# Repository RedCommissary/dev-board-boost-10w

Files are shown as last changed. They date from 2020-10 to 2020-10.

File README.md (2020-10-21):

## Плата разработчика DC/DC boost в режиме CC/CV
Устройство предназначается для изучения основ проектирования силовых преобразователей и снижения порога вхождения в разработку.
Основой служит топология синхронный boost, а алгорит CC/CV реализуется для питания мощного светодиода. Питание преобразователя
осуществляется через тот же порт USB type C, через который выводятся логи и состоянии устройства.

Вид преобразователя

## 1. Технические параметры

* Тип питания: *USB type C*
* Входное напряжение: *5В ± 10%*
* Выходное напряжение: *6...12В*
* Номинальный ток: *3А*
* Защиты: *OVP, OCP, UVLO, перегрев*
* Интерфейсы: *USB*
* Габаритные размеры: *60х40х8 мм*

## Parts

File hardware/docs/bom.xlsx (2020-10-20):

Designator | Value | PartNumber | Manufacturer | Quantity | Comment | HelpURL
C1, C11 | 470pF | CL10C471JB8NNNC | Yageo | 2 | Ceramic capacitor, 470pF, NPO, ±5%, 50V, 0603, -55...+125°C | https://www.digikey.com/product-detail/en/samsung-electro-mechanics/CL10C471JB8NNNC/1276-1168-1-ND/3889254
C2, C3, C9, C10 | 22μF | CL32B226KAJNNNE | Samsung | 4 | Ceramic capacitor, 22μF, X7R, ±10%, 25V, 1210, -55...+125°C | https://www.digikey.com/product-detail/en/samsung-electro-mechanics/CL32B226KAJNNNE/1276-3392-1-ND/3891478
C4, C5, C6, C15, C16, C25 | 0.01μF | CL10B103KB8NNNC | Samsung | 6 | Ceramic capacitor, 0.01μF, X7R, ±10%, 50V, 0603, -55...+125°C | https://www.digikey.com/product-detail/en/samsung-electro-mechanics/CL10B103KB8NNNC/1276-1009-1-ND/3889095
C7 | 1μF | CL10B105KA8NNNC | Samsung | 1 | Ceramic capacitor, 1μF, X7R, ±10%, 25V, 0603, -55...+125°C | https://www.digikey.com/product-detail/en/samsung-electro-mechanics/CL10B105KA8NNNC/1276-1184-1-ND/3889270
C8, C12, C13, C26, C31, C32, C34 | 4.7μF | CL10B475KQ8NQNC | Samsung | 7 | Ceramic capacitor, 4.7μF, X7R, ±10%, 6.3V, 0603, -55...+125°C | https://www.digikey.com/product-detail/en/samsung-electro-mechanics/CL10B475KQ8NQNC/1276-2087-6-ND/3892601
C14, C20, C21, C22, C23, C24, C27, C28, C33, C35 | 0.1μF | CL10B104KB8NNNL | Samsung | 10 | Ceramic capacitor, 0.1μF, X7R, ±10%, 50V, 0603, -55...+125°C | https://www.digikey.com/product-detail/en/samsung-electro-mechanics/CL10B104KB8NNNL/1276-CL10B104KB8NNNLCT-ND/10320686
C17, C18, C19 | 2.2μF | CL10B225KP8NFNC | Samsung | 3 | Ceramic capacitor, 2.2μF, X7R, ±10%, 10V, 0603, -55...+125°C | https://www.digikey.com/product-detail/en/samsung-electro-mechanics/CL10B225KP8NFNC/1276-2016-1-ND/3890102
C29, C30 | 12pF | CL10C120JB8NNNC | Samsung | 2 | Ceramic capacitor, 12pF, NPO, ±10%, 50V, 0603, -55...+125°C | https://www.digikey.com/product-detail/en/samsung-electro-mechanics/CL10C120JB8NNNC/1276-1254-1-ND/3889340
D1 |  | INA180A3IDBVR | Texas Instruments | 1 | IC current monitor, ±1.5%, 100V/V, -0.3...+26V, -40...+125°C, SOT23-5 | https://www.digikey.com/product-detail/en/texas-instruments/INA180A3IDBVR/296-47654-1-ND/8133023
D2 |  | MP1907GQ-Z | Monolithic Power Systems | 1 | Half-bridge gate driver, 100V, 500kHz, ±2.5A, supply 4.5...18V, -40...+125°C, 10-VFDFN (3x3) | https://www.digikey.com/product-detail/en/monolithic-power-systems-inc/MP1907GQ-Z/1589-1544-1-ND/9433310
D3 |  | TLV62568DBV | Texas Instruments | 1 | DC/DC buck converter, input 2.5...5.5V, 1.5MHz, output 0.6V, 1A, -40...+85°C, SOT23-5 | https://www.digikey.com/product-detail/en/texas-instruments/TLV62568DBVT/296-47387-1-ND/7688580
D4 |  | STM32F334C4T6 | STMicroelectronics | 1 | IC microcontroller, 32-Bit, Cortex-M4, 72MHz, 64KB, 12KB, 2...3.6V, -40...+85°C, 48-LQFP | https://www.digikey.com/en/products/detail/stmicroelectronics/STM32F334C4T6/4989170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
D5 |  | CP2102N-A02-GQFN28 | Silicon Labs | 1 | IC usb-to-uart bridge, USB2.0, 3...3.6V, -40...+85°C, 28-VFQFN | https://www.digikey.com/product-detail/en/silicon-labs/CP2102N-A02-GQFN28/336-5889-ND/9863477
FU1 |  | ERB-RG3R00V | Panasonic | 1 | ='='Electromechanics relay'+', '+'32VDC'+', '+'3A'+', '+'1206 case'+', '+Temperature' | https://www.digikey.com/product-detail/en/panasonic-electronic-components/ERB-RG3R00V/P16741CT-ND/4280098
L1 | 33μH | SRP1038C-330M | Bourns | 1 | Fixed inductor, 33μH, ±20%, SRP1038C series, 4A, -40...+125°C | https://www.digikey.com/product-detail/en/bourns-inc/SRP1038C-330M/SRP1038C-330MCT-ND/10249152
L2 | 10μH | SDR0302-100ML | Codaca | 1 | Fixed inductor, 10μH, ±20%, SP32 series, 900mA, -40...+125°C | https://www.digikey.com/product-detail/en/bourns-inc/SDR0302-100ML/SDR0302-100MLCT-ND/2127048
L3 | 10μH | LQM18FN100M00D | Murata Electronics | 1 | Fixed inductor, 10μH, ±20%, 0603, 50mA, -55...+125°C | https://www.digikey.com/product-detail/en/murata-electronics-north-america/LQM18FN100M00D/490-4025-1-ND/1016285
R1 | 0.02R | PF1206FRF070R02L | Yageo | 1 | Resistor film, 0.02R, ±1%, 1206, 0.25W, -55...+125°C | https://www.digikey.com/product-detail/en/yageo/PF1206FRF070R02L/311-0-02AJCT-ND/2178365
R2, R3, R17, R30, R31, R32, R34, R36, R39, R40, R43 | 1k | RC0603FR-071KL | Yageo | 11 | Resistor film, 1k, ±1%, 0603, 0.1W, -55...+125°C | https://www.digikey.com/product-detail/en/yageo/RC0603FR-071KL/311-1-00KHRCT-ND/729790
R4, R5, R41, R42 | 22R | RC0603FR-0722RL | Yageo | 4 | Resistor film, 22R, ±1%, 0603, 0.1W, -55...+125°C | https://www.digikey.com/product-detail/en/yageo/RC0603FR-0722RL/311-22-0HRCT-ND/730002
R6 | 47k | RC0603FR-0747KL | Yageo | 1 | Resistor film, 47k, ±1%, 0603, 0.1W, -55...+125°C | https://www.digikey.com/product-detail/en/yageo/RC0603FR-0747KL/311-47-0KHRCT-ND/730200
R7, R8, R21, R27, R28, R29 | 120R | RC0603JR-07120RL | Yageo | 6 | Resistor film, 120R, ±5%, 0603, 0.1W, -55...+125°C | https://www.digikey.com/product-detail/en/yageo/RC0603JR-07120RL/311-120GRCT-ND/729653
R9, R19, R22, R23 | 10k | RC0603FR-0710KL | Yageo | 4 | Resistor film, 10k, ±1%, 0603, 0.1W, -55...+125°C | https://www.digikey.com/product-detail/en/yageo/RC0603FR-0710KL/311-10-0KHRCT-ND/729827
R10, R15 | 1R6 | RC0603JR-071R6L | Yageo | 2 | Resistor film, 1R6, ±5%, 0603, 0.1W, -55...+125°C | https://www.digikey.com/product-detail/en/yageo/RC0603JR-071R6L/311-1-6GRCT-ND/729638
R11, R12, R13, R14, R16, R24, R25, R26, R37, R38 | 10k | RC0603JR-0710KL | Yageo | 10 | Resistor film, 10k, ±5%, 0603, 0.1W, -55...+125°C | https://www.digikey.com/product-detail/en/yageo/RC0603JR-0710KL/311-10KGRCT-ND/729647
R18 | 0.2R | RL1210FR-070R2L | Yageo | 1 | Resistor film, 0.2R, ±1%, 1210, 0.5W, -55...+125°C | https://www.digikey.com/product-detail/en/yageo/RL1210FR-070R2L/311-0-2NACT-ND/3886121
R20 | 45k3 | RC0603FR-0745K3L | Yageo | 1 | Resistor film, 45k3, ±1%, 0603, 0.1W, -55...+125°C | https://www.digikey.com/product-detail/en/yageo/RC0603FR-0745K3L/311-45-3KHRCT-ND/730192
R33 | 4k7 | NCP18XM472J03RB | Murata | 1 | NTC resistor, 4k7, ±5%, 0603, 3500K, -55...+125°C | https://www.digikey.com/en/products/detail/murata-electronics/NCP18XM472J03RB/588460
R35, R44, R45 | 5k1 | RC0603FR-075K1L | Yageo | 3 | Resistor film, 5k1, ±1%, 0603, 0.1W, -55...+125°C | https://www.digikey.com/product-detail/en/yageo/RC0603FR-075K1L/311-5-10KHRCT-ND/730215
SB1, SB2, SB3 |  | PTS636 SM43 | C&K | 3 | Tactile button, 6x3.5mm | https://www.digikey.com/product-detail/en/c-k/PTS636-SM43-SMTR-LFS/CKN12310-1-ND/10071745
VD1, VD2 |  | 150060VS75000 | Wurth | 2 | LED, 20mA, 2V, 0603, -55...+150°C | https://www.digikey.com/product-detail/en/w-rth-elektronik/150060VS75000/732-4980-1-ND/4489904
VD3, VD9 |  | 150060BS75000 | Wurth | 2 | LED, 20mA, 3.2V, 0603, -55...+150°C | https://www.digikey.com/product-detail/en/w-rth-elektronik/150060BS75000/732-4966-1-ND/4489893, https://www.digikey.com/product-detail/en/wurth-electronics-inc/150060BS75000/732-4966-1-ND/4489893
VD4, VD5, VD6, VD7 |  | 150060RS75000 | Wurth | 4 | LED, 20 mA, 2V, 0603, -55...+150°C | https://www.digikey.com/product-detail/en/w-rth-elektronik/150060RS75000/732-4978-1-ND/4489899
VD8 |  | 150060YS75000 | Wurth | 1 | LED, 20mA, 2V, 0603, -55...+150°C | https://www.digikey.com/product-detail/en/wurth-electronics-inc/150060YS75000/732-4981-1-ND/4489907
VT1, VT2 |  | RQ3G100GNTB | Rohm Semiconductor | 2 | MOSFET N-channel transistor, 40V, 10A, 8.4nC, 2W, 14.3mOhm, 615pF, 8-PowerVDFN (3x3), -55...+150°C | https://www.digikey.com/product-detail/en/rohm-semiconductor/RQ3G100GNTB/RQ3G100GNTBCT-ND/5042551
X3 |  | SM05B-GHS | JST | 1 | Connector, 5pin, 1.25mm, 50VDC, 1A | https://www.digikey.com/product-detail/en/jst-sales-america-inc/SM05B-GHS-TB-LF-SN/455-1567-1-ND/807835
X4 |  | TYPE-C-31-M-12 | Korean Hroparts | 1 | USB Type C, 3A | https://lcsc.com/product-detail/USB-Type-C_Korean-Hroparts-Elec-TYPE-C-31-M-12_C165948.html
Z1 |  | ECS-80-12-33-JGN-TR | ECS | 1 | Crystal, 8MHz, 12pF, ±30ppm, case 3225, -40...+85°C | https://www.digikey.com/product-detail/en/ecs-inc/ECS-80-12-33-JGN-TR/50-ECS-80-12-33-JGN-CT-ND/10478769

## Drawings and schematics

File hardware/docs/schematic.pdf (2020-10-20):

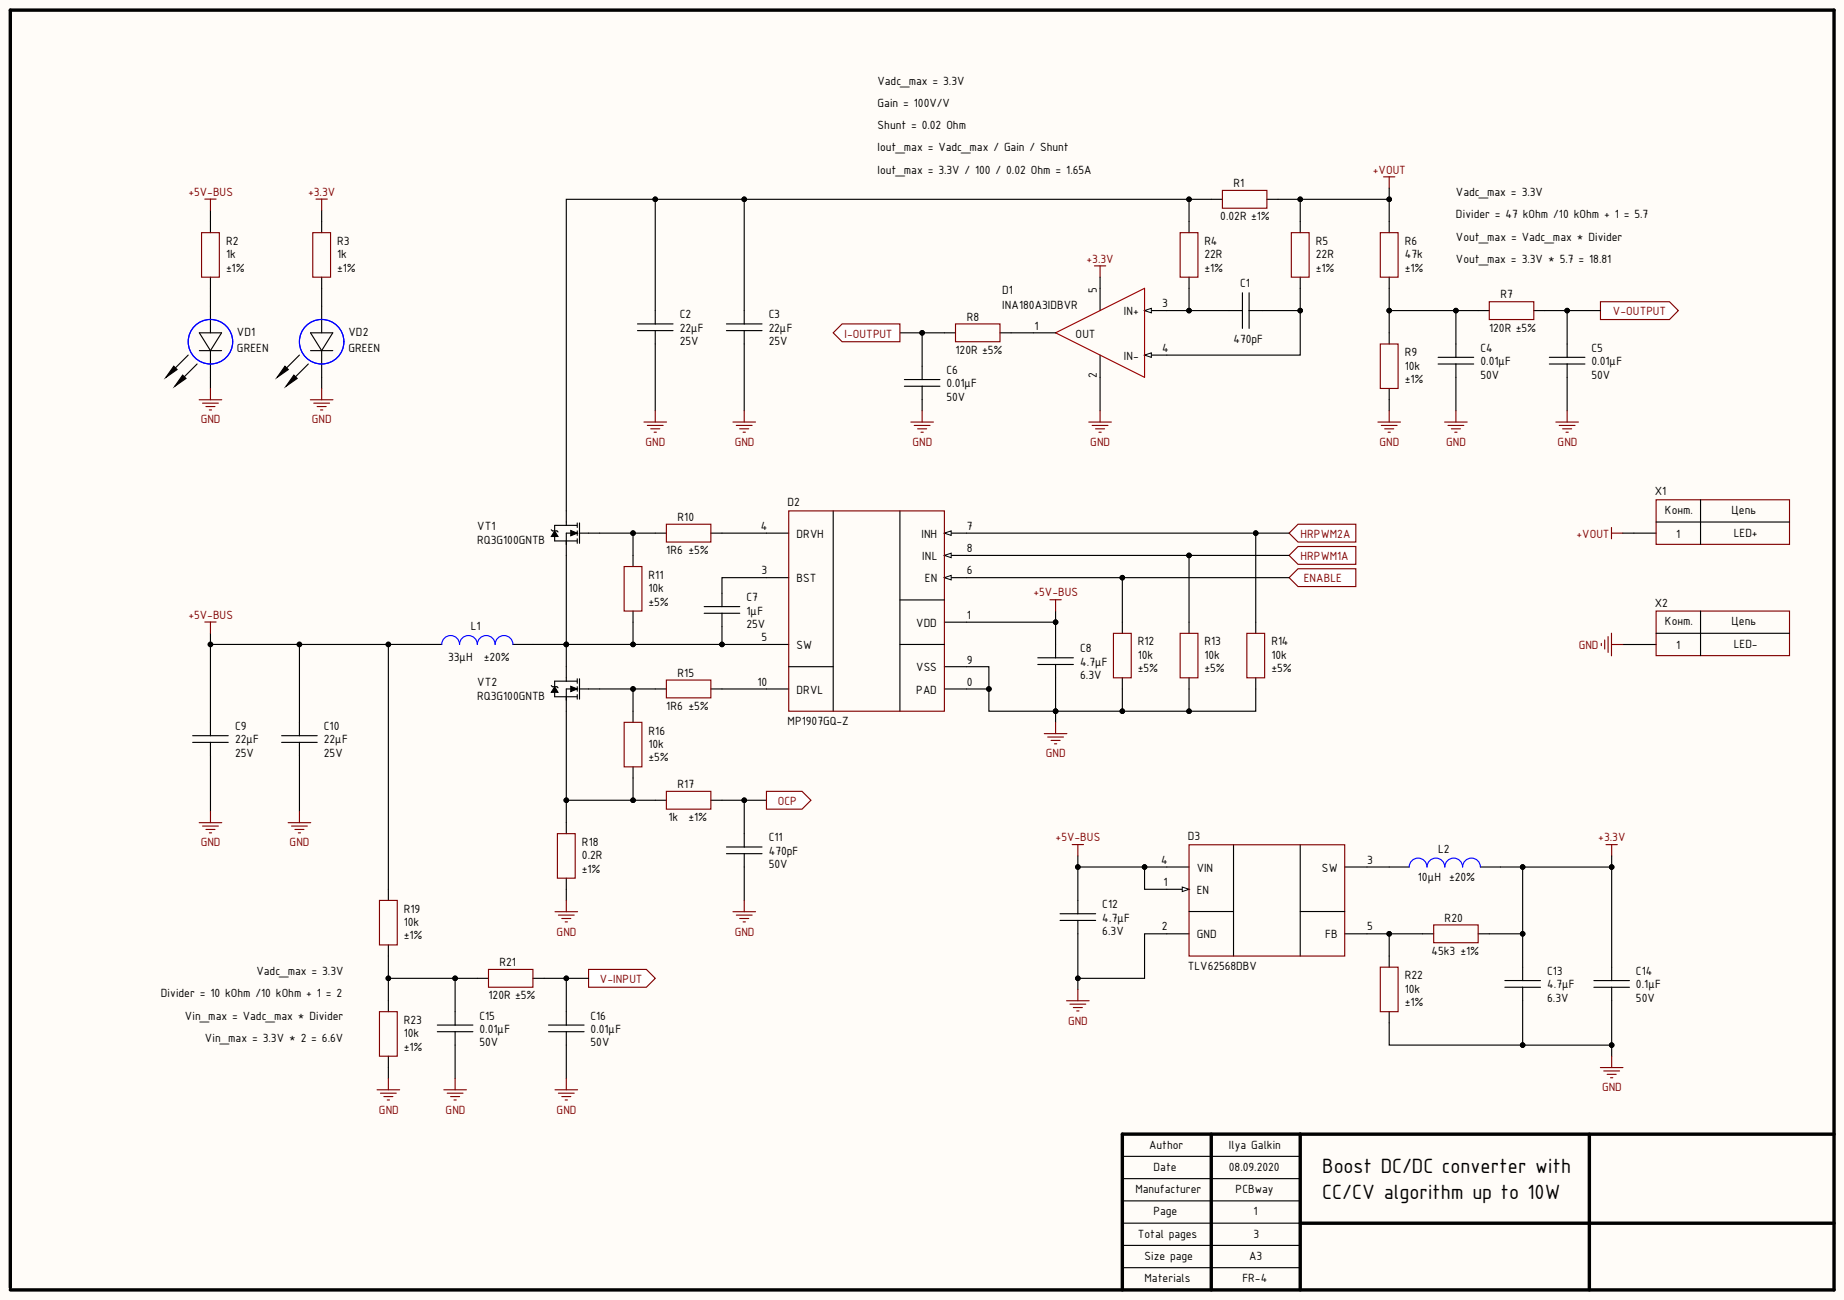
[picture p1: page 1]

Конт. | Цепь

1 | LED+

1 | LED-

Author | Ilya Galkin | Boost DC/DC converter with CC/CV algorithm up to 10W

Date | 08.09.2020

Manufacturer | PCBway

Page

Total pages

Size page | A3

Materials | FR-4

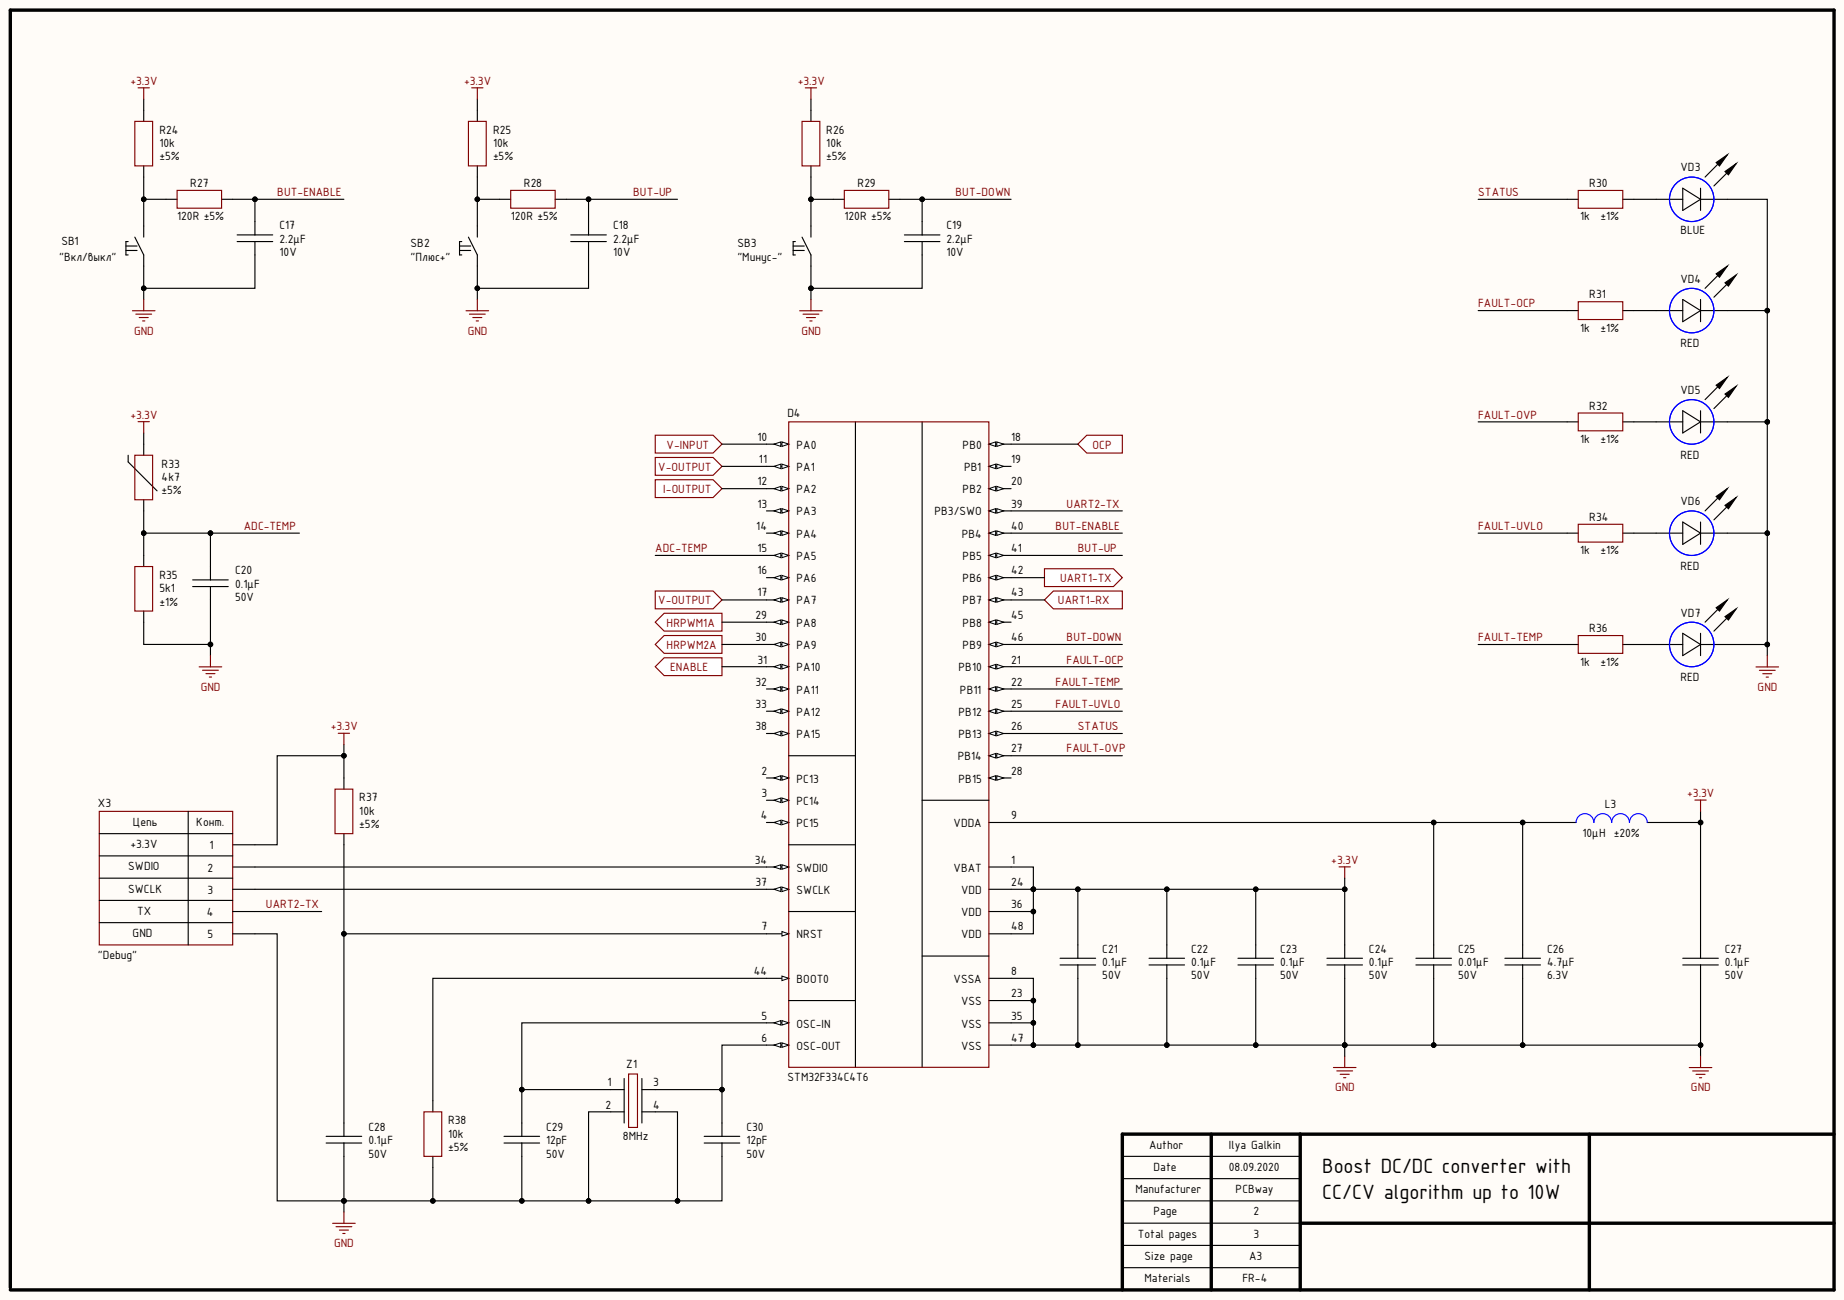
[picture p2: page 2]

PC15 4 | VBAT VDD VDD

Цепь | Конт.

SWDIO | 2

SWDIO 34 | 1 +3.3V 0.1μF | 0.01μF | 4.7μF

SWCLK | 3
4 | UART2-TX TX

SWCLK 37 | 24

NRST 7 | 36 | 0.1μF | 0.1μF | 0.1μF

GND | 5

Author | Ilya Galkin | Boost DC/DC converter with CC/CV algorithm up to 10W

Date | 08.09.2020

Manufacturer | PCBway

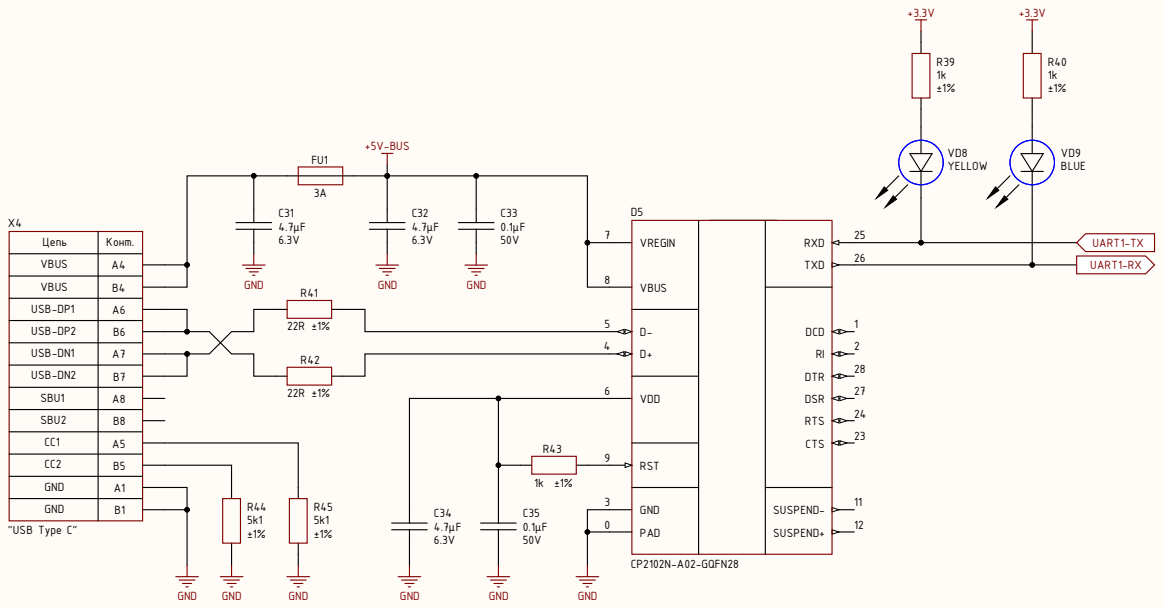
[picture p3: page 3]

Цепь | Конт.

VBUS | A4

VBUS | B4

USB-DP1 | A6

USB-DP2 | B6

USB-DN1 | A7

USB-DN2 | B7
SBU1 | A8 | 22R ±1%

SBU2 | B8

R43 | RST 9

Author | Ilya Galkin | Boost DC/DC converter with CC/CV algorithm up to 10W

Date | 08.09.2020

Manufacturer | PCBway

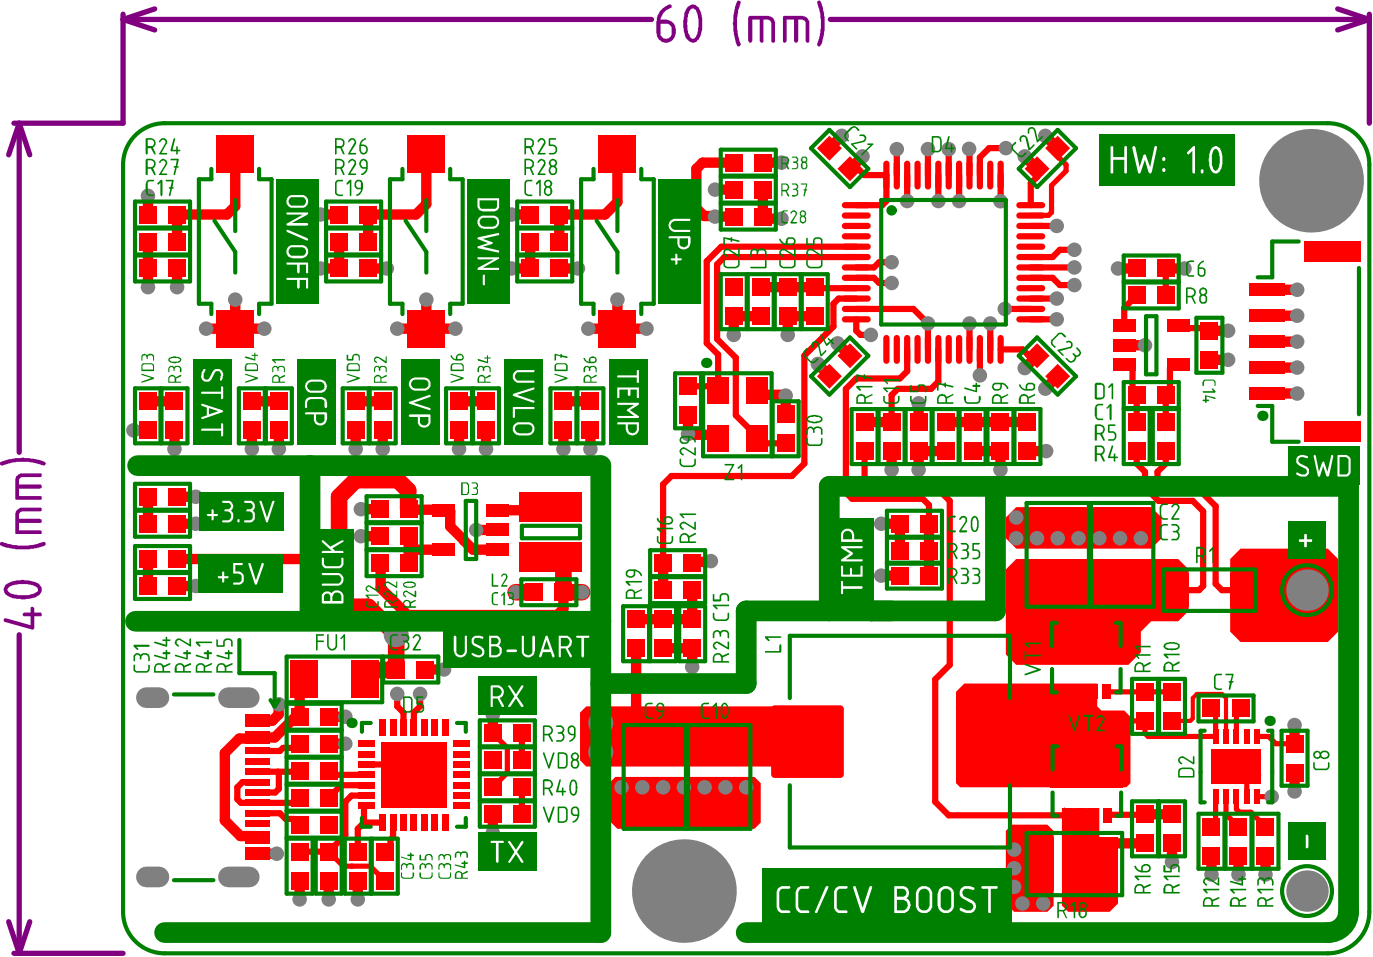
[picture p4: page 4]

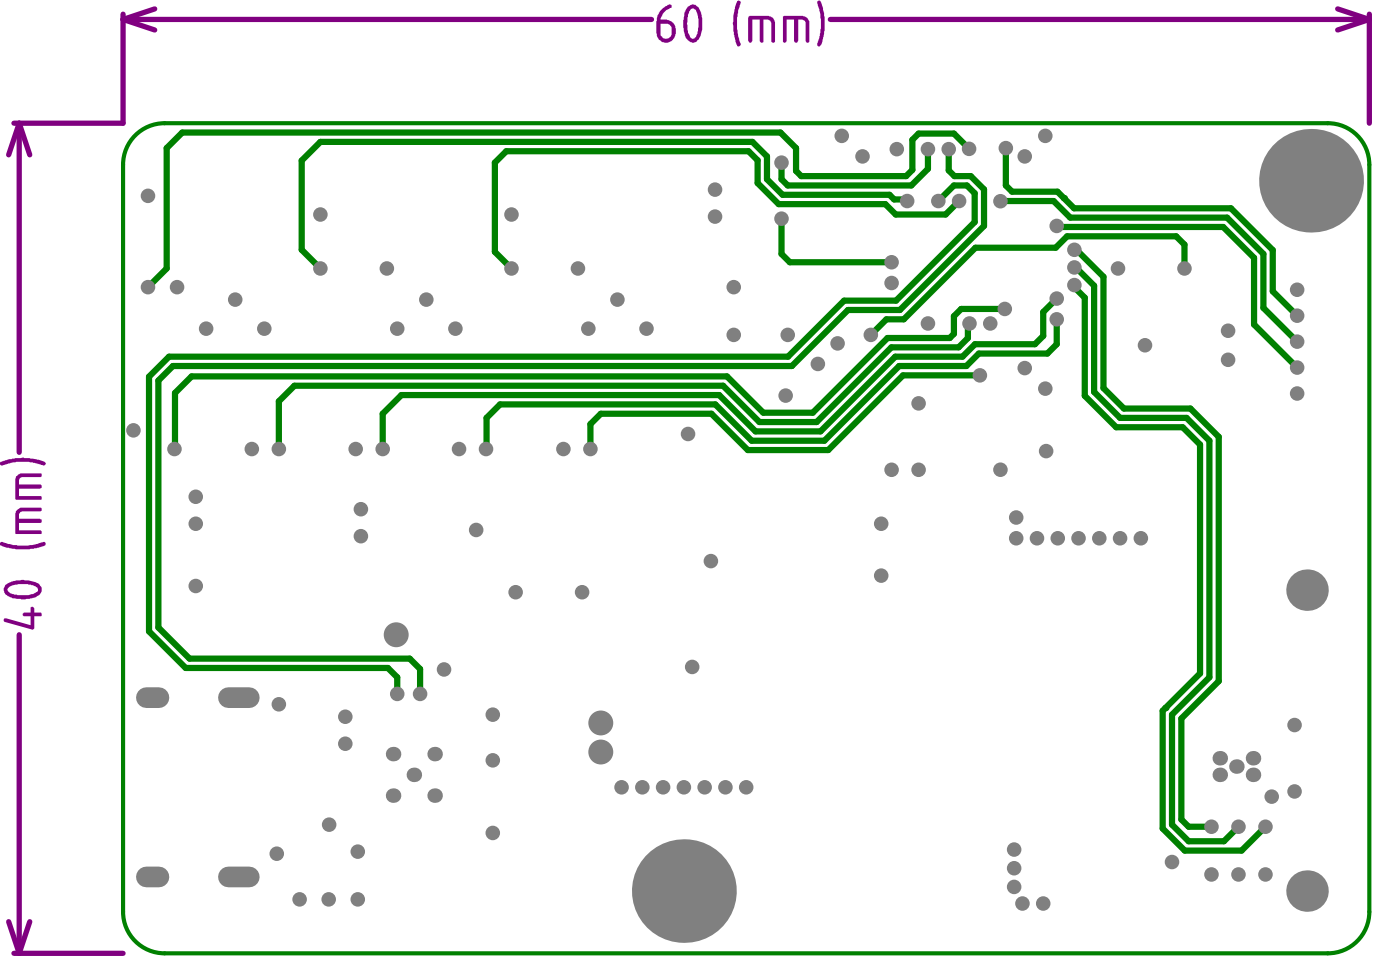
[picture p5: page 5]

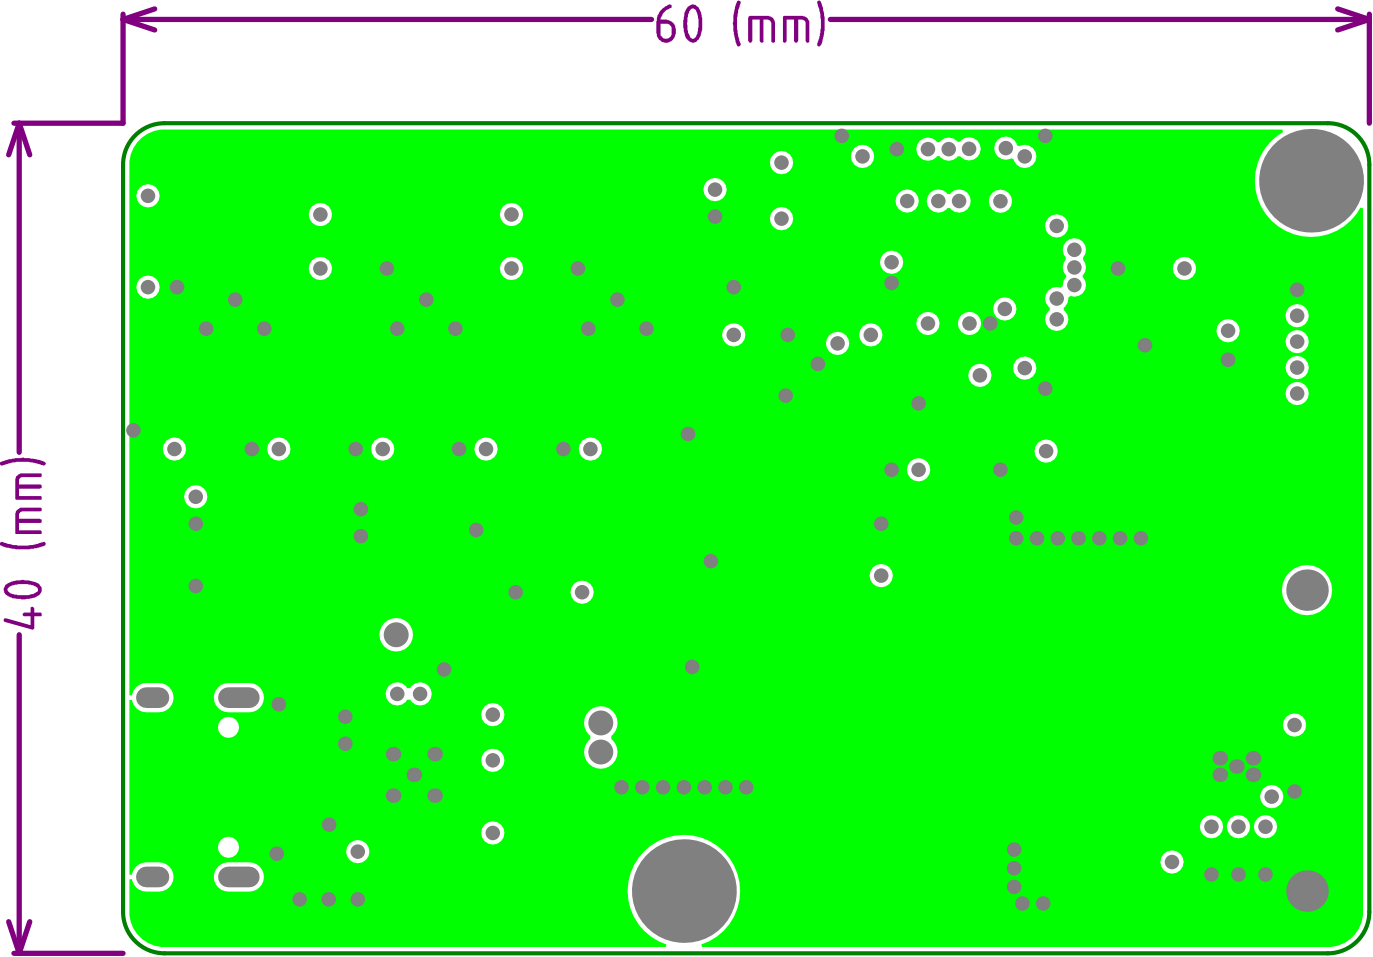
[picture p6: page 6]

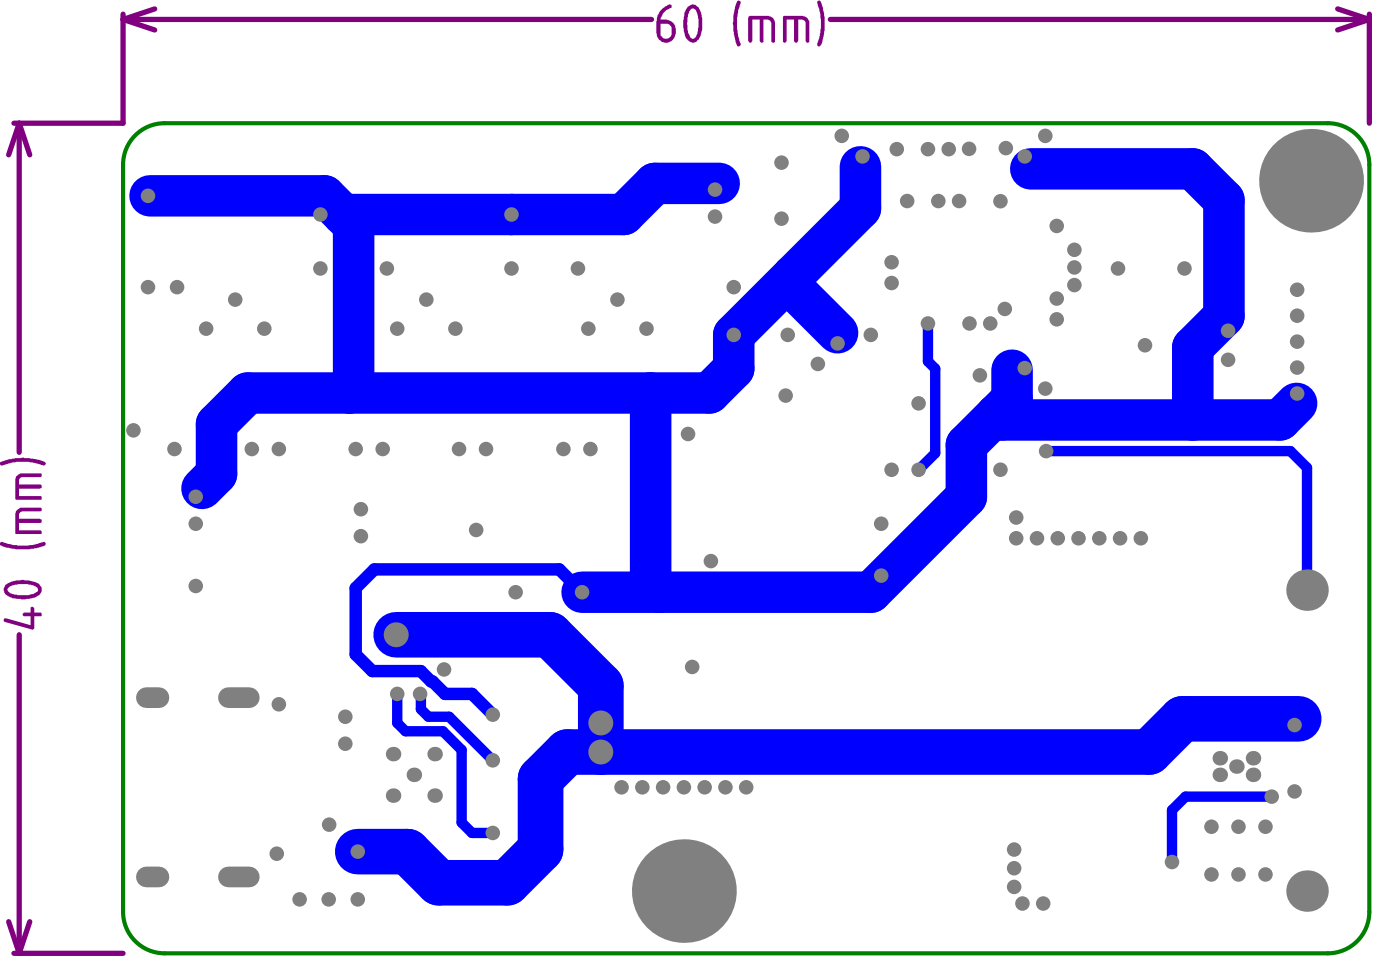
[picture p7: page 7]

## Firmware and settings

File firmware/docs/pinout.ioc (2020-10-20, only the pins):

Mcu.UserName=STM32F334C4Tx
PA0.GPIO_Label=ADC1-IN1-V-INPUT
PA0.Signal=ADC1_IN1
PA1.GPIO_Label=ADC1-IN2-V-OUTPUT
PA1.Signal=ADC1_IN2
PA10.GPIO_Label=ENABLE-DRIVER
PA10.Signal=GPIO_Output
PA13.GPIO_Label=DEBUG-SWDIO
PA13.Signal=SYS_JTMS-SWDIO
PA14.GPIO_Label=DEBUG-SWCLK
PA14.Signal=SYS_JTCK-SWCLK
PA2.GPIO_Label=ADC1-IN3-I-OUTPUT
PA2.Signal=ADC1_IN3
PA5.GPIO_Label=ADC2-IN2-TEMP
PA5.Signal=ADC2_IN2
PA7.GPIO_Label=COMP2-V-OUTPUT
PA7.Signal=COMP2_INP
PA8.GPIO_Label=HRPWM-CHA1-LO
PA8.Signal=HRTIM1_CHA1
PA9.GPIO_Label=HRPWM-CHA2-HO
PA9.Signal=HRTIM1_CHA2
PB0.GPIO_Label=COMP4-OCP
PB0.Signal=COMP4_INP
PB10.GPIO_Label=LED-FAULT-OCP
PB10.Signal=GPIO_Output
PB11.GPIO_Label=LED-FAULT-TEMP
PB11.Signal=GPIO_Output
PB12.GPIO_Label=LED-FAULT-UVLO
PB12.Signal=GPIO_Output
PB13.GPIO_Label=LED-STATUS
PB13.Signal=GPIO_Output
PB14.GPIO_Label=LED-FAULT-OVP
PB14.Signal=GPIO_Output
PB3.GPIO_Label=DEBUG-SWO/TX
PB3.Signal=USART2_TX
PB4.GPIO_Label=BUTTON-ON/OFF
PB4.Signal=GPIO_Input
PB5.GPIO_Label=BUTTON-UP+
PB5.Signal=GPIO_Input
PB6.Signal=USART1_TX
PB7.Signal=USART1_RX
PB8.GPIO_Label=BUTTON-DOWN-
PB8.Signal=GPIO_Input

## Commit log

2020-09-07 new: Завершил принципиальную схему отладки
    [converter.SchDoc, dev-board-boost.PrjPcb, dsp.SchDoc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]
2020-09-07 docs: Загрузил предварительный pinout и документацию на МК
2020-09-07 docs: Добавил в исключения папки History и Preview от Altium
2020-10-16 new: Выполнил трассировку силовой части boost и usb-uart конвертера
    [converter.SchDoc, dev-board-boost.PrjPcb, dsp.SchDoc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]
2020-10-20 new: Завершил трассировку печатной платы
    [converter.SchDoc, dev-board-boost.PrjPcb, dsp.SchDoc]
2020-10-20 docs: Обновил pinout в полном соответствии с финальной версией схемы
2020-10-20 docs: Сгенерировал КД: gerber, bom, схему, 3d модель, P&P файл
    [bom.xlsx]
2020-10-21 docs: Добавил описание устройства
